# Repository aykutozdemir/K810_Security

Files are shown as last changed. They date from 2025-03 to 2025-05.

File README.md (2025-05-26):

# K810_Security

## PlatformIO Build Instructions

### Prerequisites
- Python and pip installed
- PlatformIO installed (`pip install platformio`)

### Compilation
To compile the project, use one of these commands:
```bash
pio run
# or
platformio run
```

### Additional Useful Commands
- `pio run -t upload` - Compile and upload to the board
- `pio run -t clean` - Clean the build directory
- `pio run -t program` - Compile and program the board
- `pio device monitor` - Open the serial monitor

The compiled firmware will be placed in the `.pio/build/promicro16/` directory.

## Build Scripts

The project includes several Python scripts that enhance the build process:

### generate_version.py
Automatically increments and manages build version numbers. The version is stored in `version.txt` and is included in the firmware as a build flag.

### asembly_analyzer.py
Analyzes the assembly code of the compiled firmware, providing:
- Disassembly of the firmware
- Analysis of Interrupt Service Routines (ISRs)
- Register usage statistics
- Stack push/pop balance checking

Usage:
```bash
pio run -t disasm  # Generate and analyze disassembly
```

### map_analyzer.py
Analyzes the memory map of the compiled firmware, showing:
- Symbol sizes and addresses
- Memory usage by function
- Type of memory (code, data, BSS)

Usage:
```bash
python map_analyzer.py [--file path/to/firmware.elf] [--filter tTbBdD]
```

### custom_build.py
Applies custom build flags and optimizations:
- Disables unused parameter warnings
- Applies C++ specific optimizations
- Configures build environment for Arduino framework

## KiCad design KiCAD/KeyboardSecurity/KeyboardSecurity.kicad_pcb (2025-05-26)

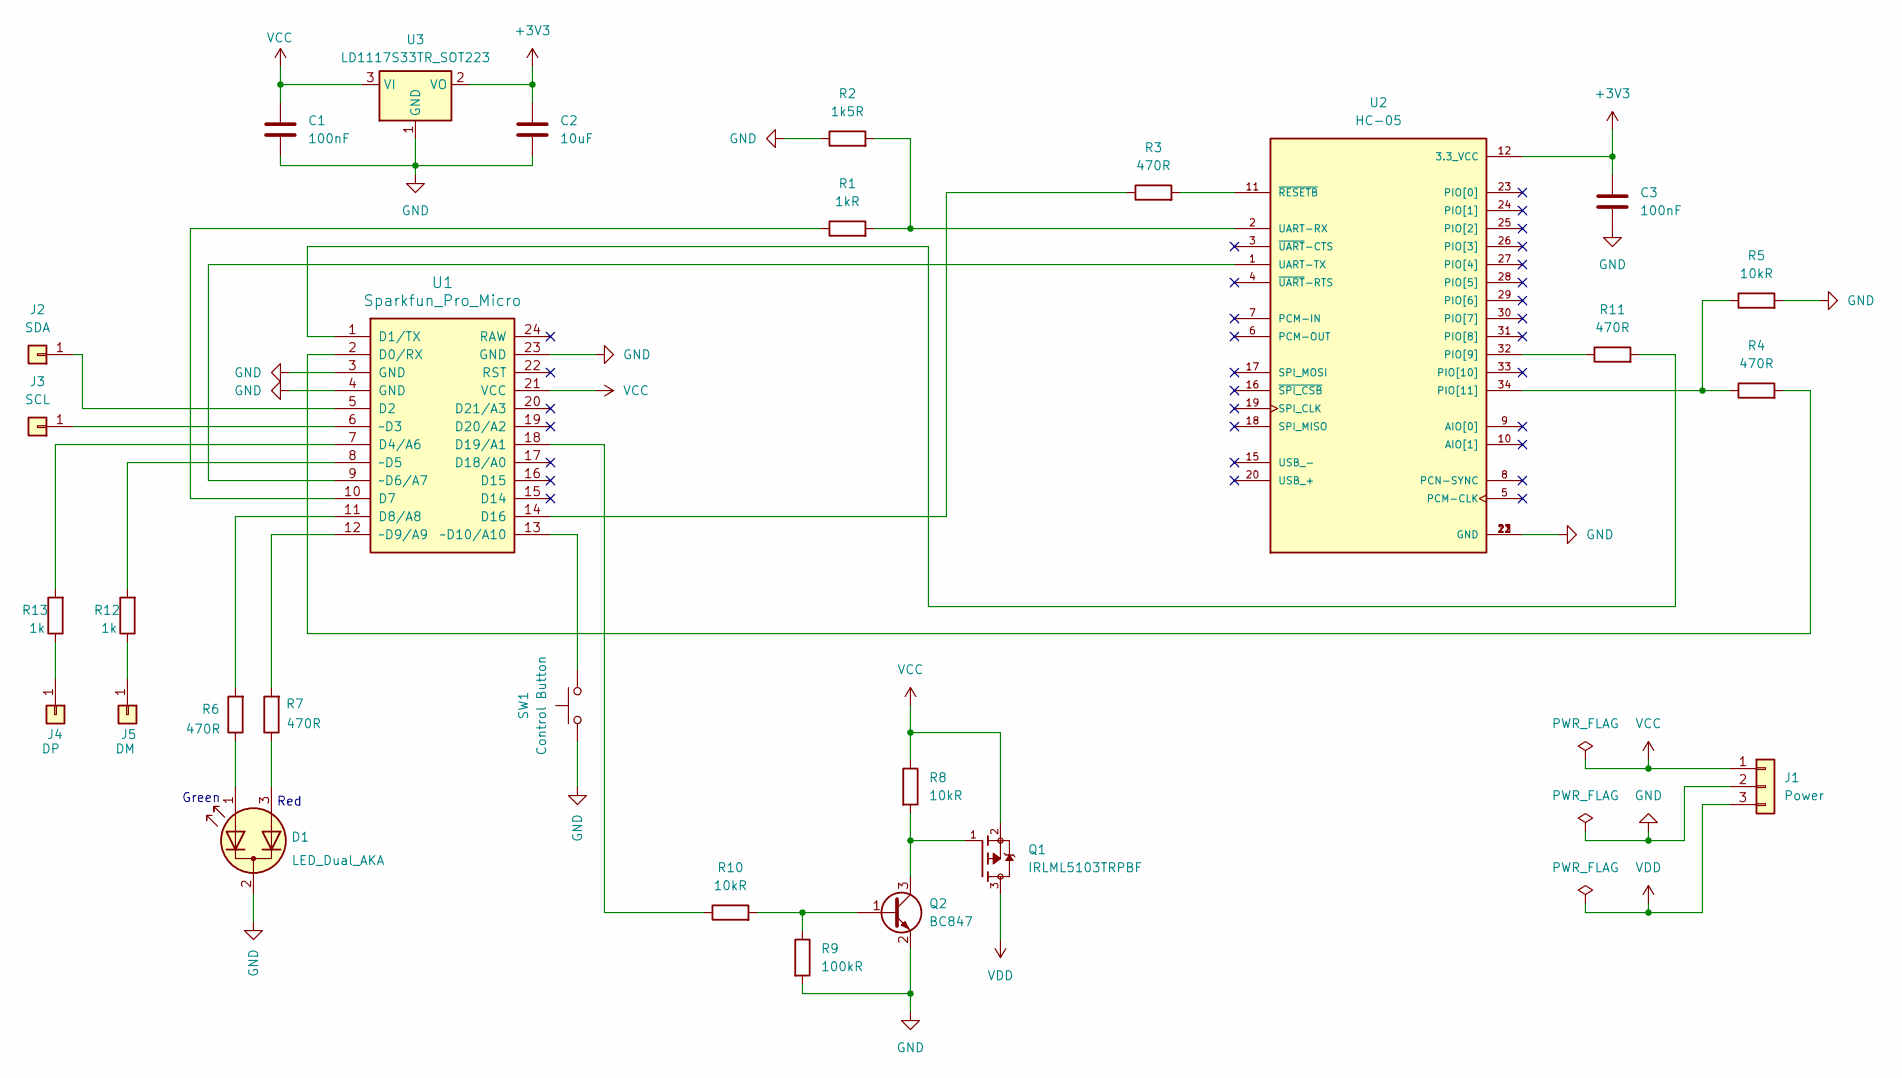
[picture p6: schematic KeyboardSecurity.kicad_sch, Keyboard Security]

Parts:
C1, C3: 100nF; C_0805_2012Metric
C2: 10uF; C_1812_4532Metric
D1: LED_Dual_AKA; PinHeader_1x03_P2.54mm_Vertical
J1: Power; PinHeader_1x03_P2.54mm_Vertical
J2: SDA; PinHeader_1x01_P2.54mm_Vertical
J3: SCL; PinHeader_1x01_P2.54mm_Vertical
J4: DP; PinHeader_1x01_P2.54mm_Vertical
J5: DM; PinHeader_1x01_P2.54mm_Vertical
Q1: IRLML5103TRPBF; SOT95P237X112-3N; PARTREV 4/24/2014
Q2: BC847; SOT-23
R1: 1kR; R_0805_2012Metric
R2: 1k5R; R_0805_2012Metric
R3, R4, R6, R7, R11: 470R; R_0805_2012Metric
R5, R8, R10: 10kR; R_0805_2012Metric
R9: 100kR; R_0805_2012Metric
R12, R13: 1k; R_0805_2012Metric
SW1: Control Button; PinHeader_1x02_P2.54mm_Vertical
U1: Sparkfun_Pro_Micro
U2: HC-05; XCVR_HC-05; PARTREV v1.0
U3: LD1117S33TR_SOT223; SOT-223-3_TabPin2

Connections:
+3V3: C2.1, C3.1, U2.12 (3.3_VCC), U3.2 (VO)
GND: C1.2, C2.2, C3.2, D1.2 (K), J1.2, Q2.2 (E), R2.1, R5.2, R9.2, SW1.1, U1.3 (GND), U1.4 (GND), U1.23 (GND), U2.13 (GND), U2.21 (GND), U2.22 (GND), U3.1 (GND)
unnamed: D1.1 (A1), R6.1
unnamed: D1.3 (A2), R7.1
unnamed: J2.1, U1.5 (D2)
unnamed: J3.1, U1.6 (~D3)
unnamed: J4.1, R13.1
unnamed: J5.1, R12.1
unnamed: Q2.1 (B), R9.1, R10.2
unnamed: Q1.1, Q2.3 (C), R8.2
unnamed: R4.2, U1.2 (D0/RX)
unnamed: R11.2, U1.1 (D1/TX)
unnamed: R13.2, U1.7 (D4/A6)
unnamed: R1.1, U1.10 (D7)
unnamed: R6.2, U1.11 (D8/A8)
unnamed: R3.1, U1.14 (D16)
unnamed: R10.1, U1.18 (D19/A1)
unnamed: R12.2, U1.8 (~D5)
unnamed: U1.9 (~D6/A7), U2.1 (UART-TX)
unnamed: R7.2, U1.12 (~D9/A9)
unnamed: SW1.2, U1.13 (~D10/A10)
unnamed: R11.1, U2.32 (PIO[9])
unnamed: R4.1, R5.1, U2.34 (PIO[11])
unnamed: R1.2, R2.2, U2.2 (UART-RX)
unnamed: R3.2, U2.11 (~RESETB)
VCC: C1.1, J1.1, Q1.2, R8.1, U1.21 (VCC), U3.3 (VI)
VDD: J1.3, Q1.3

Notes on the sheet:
Red
Green

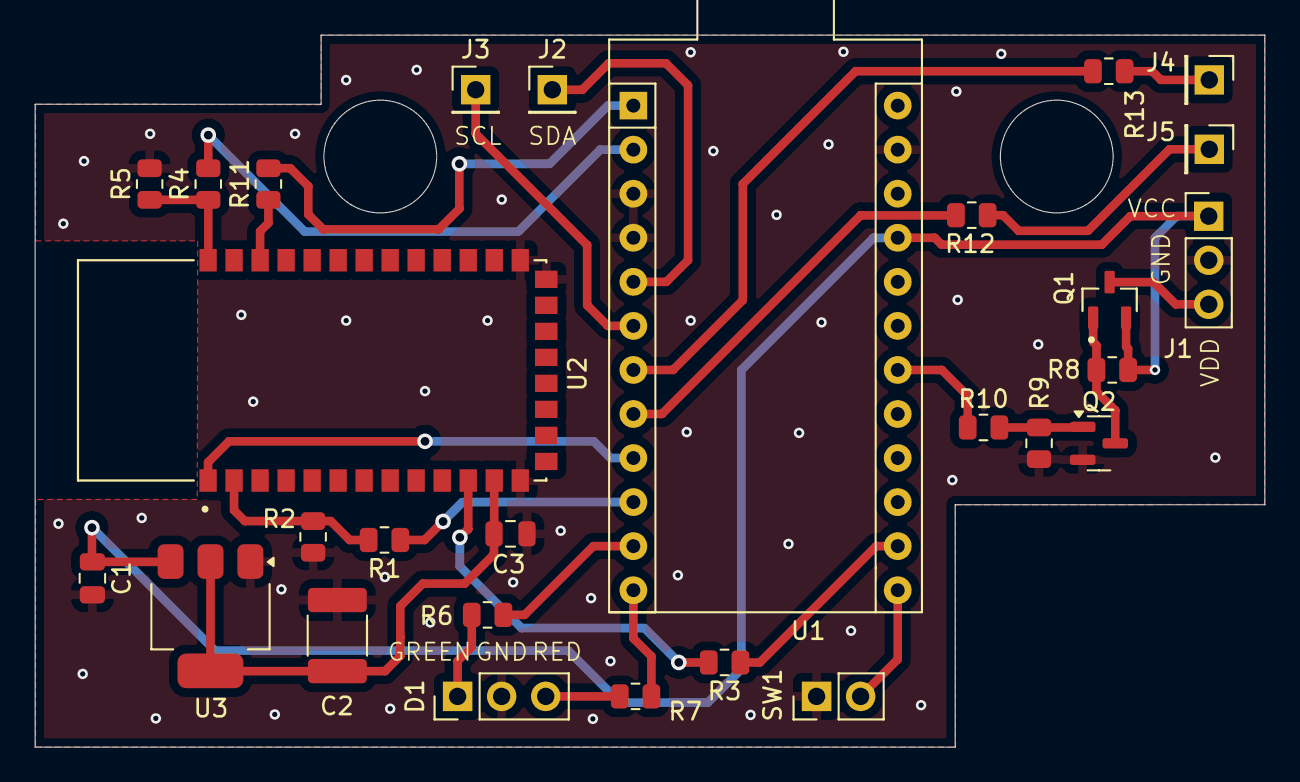
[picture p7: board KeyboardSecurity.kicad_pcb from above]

Board: 2 copper layers, 70.9 x 41.0 mm, 28 parts (0 on the bottom side), 27 nets.

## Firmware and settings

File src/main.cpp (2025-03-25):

/**
 * @file main.cpp
 * @brief Main entry point for the K810 Security device
 *
 * This file contains the main entry point for the K810 Security device.
 * It creates an instance of the K810Security class and runs the application.
 */

#include "K810Security.h"

// Create the main application instance
K810Security k810Security;

/**
 * @brief Arduino setup function
 * Initializes the application
 */
void setup()
{
    k810Security.setup();
}

/**
 * @brief Arduino main loop function
 * Runs the main application loop
 */
void loop()
{
    k810Security.loop();
}

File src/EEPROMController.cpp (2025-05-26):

// Project headers
#include "EEPROMController.h"
#include <EEPROM.h>
#include "Utilities.h"

// Arduino core
#include <Arduino.h>
#include <USBAPI.h>

#include "TraceLevel.h"
#undef CLASS_TRACE_LEVEL
#define CLASS_TRACE_LEVEL DEBUG_EEPROM_CONTROLLER
#include "TraceHelper.h"
// Constants
constexpr uint8_t EXT_EEPROM_I2C_ADDRESS = 0x50;
constexpr uint8_t EXT_EEPROM_PAGE_SIZE = 32;
constexpr uint16_t EXT_EEPROM_TOTAL_SIZE = 8192;
constexpr uint8_t INT_EEPROM_PAGE_SIZE = 32;

EEPROMController::EEPROMController(I2C &i2c)
    : Traceable(F("EEPROMController"), static_cast<Level>(DEBUG_EEPROM_CONTROLLER)), p_i2c(&i2c), m_state(IDLE), m_currentCounter(0)
{
} // end EEPROMController

EEPROMController::State EEPROMController::state() const
{
  return m_state;
} // end state

void EEPROMController::format()
{
  if (m_state == IDLE)
  {
    m_state = FORMATTING_EXTERNAL;
    p_i2c->begin();
    p_i2c->timeOut(80);
    m_currentCounter = 0;
  } // end if
} // end format

void EEPROMController::loop()
{
  switch (m_state)
  {
  case IDLE:
    break;

  case FORMATTING_EXTERNAL:
    if (!checkWriteComplete())
    {
      break;
    }

    if (m_currentCounter >= (EXT_EEPROM_TOTAL_SIZE / EXT_EEPROM_PAGE_SIZE))
    {
      p_i2c->end();
      m_state = FORMATTING_INTERNAL;
      m_currentCounter = 0;
      TRACE_INFO()
          << F("External eeprom formatting done")
          << endl;
      break;
    }

    formatExternalPage();
    break;

  case FORMATTING_INTERNAL:
    if (m_currentCounter >= EEPROM.length())
    {
      m_state = IDLE;
      m_currentCounter = 0;
      TRACE_INFO()
          << F("Internal eeprom formatting done")
          << endl;
      break;
    }

    formatInternalPages();
    break;
  } // end switch
} // end loop

bool EEPROMController::checkWriteComplete() const
{
  const uint8_t result = p_i2c->write(EXT_EEPROM_I2C_ADDRESS);

  return result == 0;
}

void EEPROMController::formatExternalPage()
{
  const uint16_t startAddress = m_currentCounter * EXT_EEPROM_PAGE_SIZE;
  const uint8_t pageData[EXT_EEPROM_PAGE_SIZE] = {0x00};

  p_i2c->write16(EXT_EEPROM_I2C_ADDRESS, startAddress, pageData, EXT_EEPROM_PAGE_SIZE);

  TRACE_DEBUG()
      << F("External eeprom page: ")
      << m_currentCounter
      << endl;

  ++m_currentCounter;
}

void EEPROMController::formatInternalPages()
{
  for (int i = 0; (i < INT_EEPROM_PAGE_SIZE) && (m_currentCounter < EEPROM.length()); ++i)
  {
    EEPROM.update(m_currentCounter, 0x00);
    ++m_currentCounter;
  }

  TRACE_DEBUG()
      << F("Internal eeprom counter: ")
      << m_currentCounter
      << endl;
}

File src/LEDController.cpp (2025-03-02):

// Project headers
#include "LEDController.h"

LEDController::LEDController(const uint8_t greenLEDPin,
                             const uint8_t redLEDPin)
    : m_greenLED(greenLEDPin), m_redLED(redLEDPin), m_state(LOCKED)
{
  m_greenLED.turnOFF();
  m_redLED.turnON();
} // end LEDController

LEDController::State LEDController::state() const
{
  return m_state;
} // end state

void LEDController::setState(const State state)
{
  if (state != m_state)
  {
    m_state = state;

    switch (m_state)
    {
    case LOCKED:
      m_greenLED.turnOFF();
      m_redLED.turnON();
      break;

    case RESETTING_BLUETOOTH:
    case FORMATTING:
      m_greenLED.turnOFF();
      m_redLED.blink(LED_FAST_BLINK_DURATION, LED_FAST_BLINK_DURATION);
      break;

    case CONNECTING:
    case PRESSING:
      m_greenLED.turnOFF();
      m_redLED.blink(LED_SLOW_BLINK_DURATION, LED_SLOW_BLINK_DURATION);
      break;

    case UNLOCKED:
      m_greenLED.turnON();
      m_redLED.turnOFF();
      break;
    } // end switch
  } // end if
} // end setState

void LEDController::loop()
{
  m_greenLED.loop();
  m_redLED.loop();
} // end loop

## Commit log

2025-02-15 Arduino K810 keypad security project
2025-02-26 Reset reason implemented, wdt isr implemented, lots of improvements on soft serial and hc05 driver
    [Globals.h]
2025-02-27 Doc formattings and bug fixes
    [Globals.h]
2025-03-02 Package interface implemented for uart
2025-03-12 Lots of improvements, comments and bug fixes
    [EEPROMController.cpp, Globals.h]
2025-03-25 Trace library implemented
2025-03-27 Traceable class implemented, lots of improvement and size optimization
2025-03-29 Traceable commands implemented
2025-03-29 Formating fixes, new trace related commands
    [EEPROMController.cpp, K810Security.cpp, K810Security.h]
2025-05-26 Project completed
    [KeyboardSecurity-B_Cu.gbr, KeyboardSecurity-B_Mask.gbr, KeyboardSecurity-B_Paste.gbr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]
